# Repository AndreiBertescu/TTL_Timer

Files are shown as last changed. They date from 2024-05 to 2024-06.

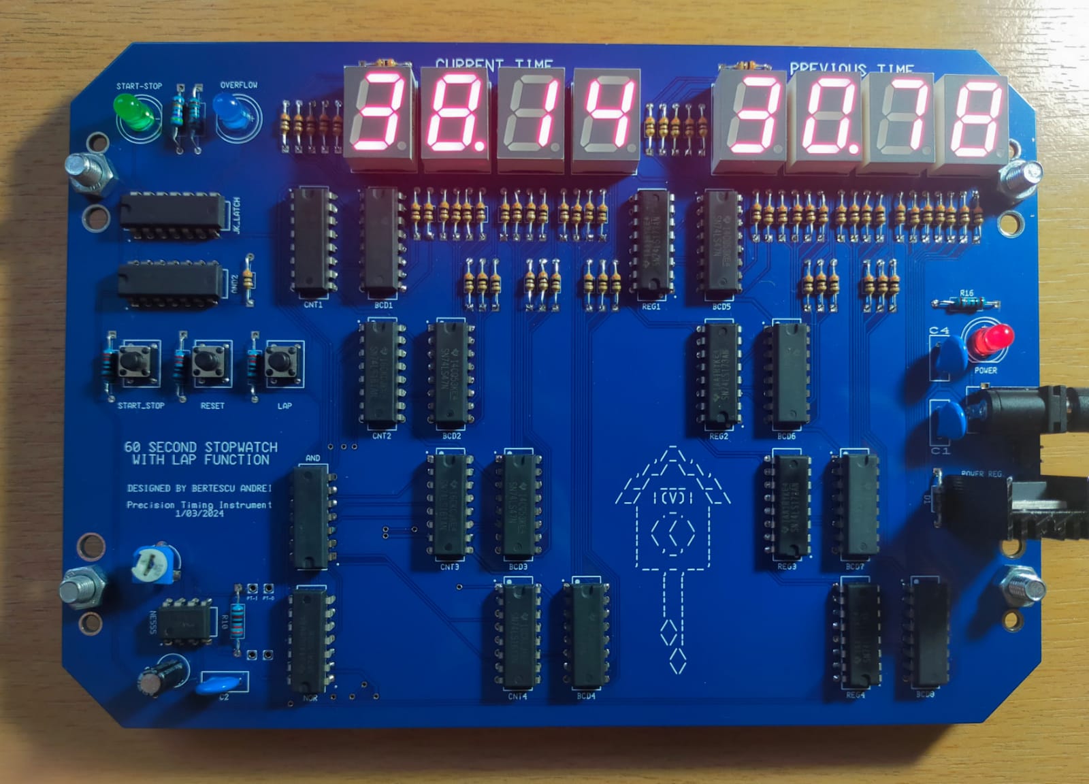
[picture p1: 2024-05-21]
Photos/Real1.jpg

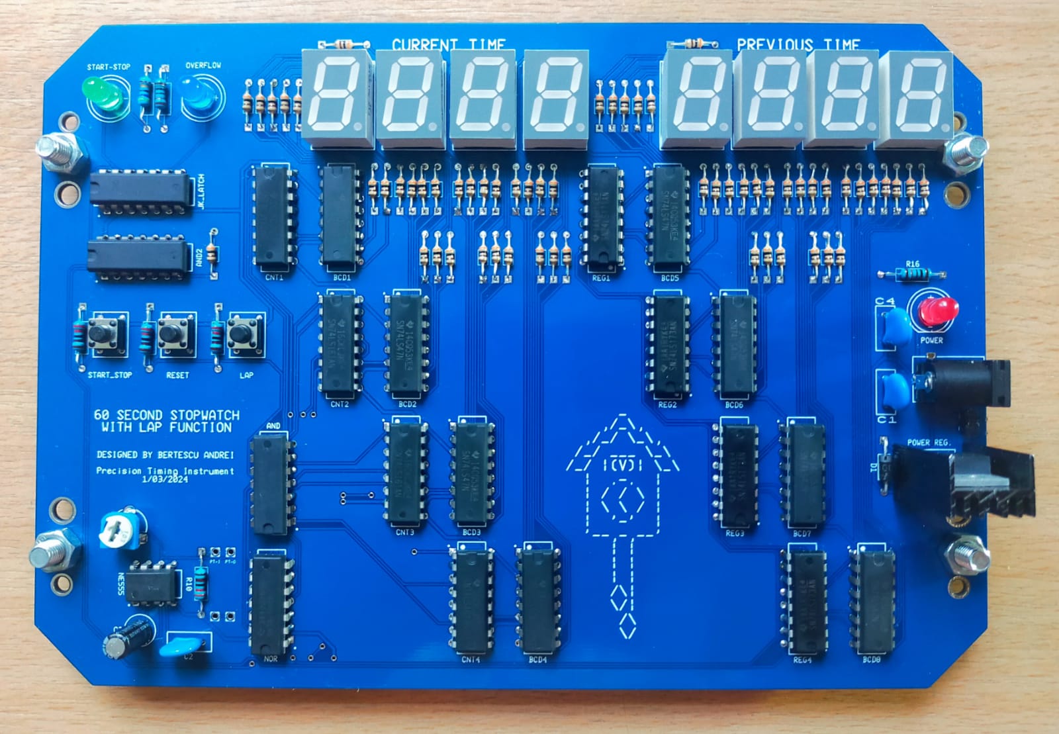
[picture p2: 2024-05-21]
Photos/Real2.jpg

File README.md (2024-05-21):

# TTL_Timer
A 60 second timer with stopwatch function, start/stop button and reset capabilities; made for a year 2 university project.

Real2

## Description and features
- There are three buttons:
  - A <strong>START_STOP</strong> button, which  pauses and unpauses, with the help of a JK flip-flop, the main timer.
  - A <strong>RESET</strong> button, which  resets both the timer and the lap time.
  - A <strong>LAP</strong> button, which , when pressed, stores the timer values to a set of four 4-bit tri-state registers.
- There are three LEDs:
  - A <strong>POWER</strong> LED, to see if the circuit board has a power supply connected.
  - A <strong>START_STOP</strong> LED, which  is tied to the button with the same name.
  - An <strong>OVERFLOW</strong> LED, which  toggles when the main timer goes over 59.99 seconds.
- 8 7-segment displays: 4 for the timer and 4 for the lap time.
- Resolution of 10ms.
- Adjustable timer for precision calibration.
- 9V barrel input with reverse polarity protection.
- 5V 2-pin header with reverse polarity protection.
- 3 sizes of mounting screws.
- All the various files (Logisim schematic, Multisim schematic, Ultiboard layout) are included, along with the Gerber exports and a Bill of materials.

## Testing and designing steps

The first step was to design the logic circuit in [Logisim Evolution](https://github.com/logisim-evolution/logisim-evolution), for an easy to change design, while also not having to worry about the various electrical rules.

Logisim

<br>The next steps were to draw the electrical schematic and test it. For these steps, the Multisim/Ultiboard duo from National Instruments was used. Multisim, in particular, was chosen over more mainstream programs such as KiCad for its real-time simulation feature, which helped ensure the PCB would work as intended from the first try.

<p align="center">
  
  
</p>

<br>Next was drawing the layout:
- The PCB is a 19.0 cm x 13.3 cm 2-layer board.
- It has 3mm, 4mm, and 5mm mounting holes intended for standoff screws.
- It has a GND copper plane on both layers.
- All signal traces are 0.254 mm, while the 5V power trace is double the size, at 0.508 mm.
- An additional hole for the power regulator heatsink was added.
- Four additional holes were added to allow replacing the 555-timer potentiometer with two resistors tied in series.
- Proper names were added for the various components, along with description text and a nice drawing.



The final steps were to order the parts, the PCB, and assemble the board.

- The various components were ordered from [TME](https://www.tme.eu/en/)
- The PCB was ordered from [Jlcpcb](https://jlcpcb.com/)

## Components
- 8x 7-segment displays
- 3x LEDs
- 3x 10nF ceramic capacitors
- 1x 1uF electrolytic capacitor
- 1x 1N4002 rectifier diode
- 1x 10k trimmer potentiometer
- 3x push switches
- 1x barrel connector
- 2x header pins
- 1x LM7805 power regulator
- 4x 4-bit tri-state registers
- 8x 4-bit BCD decoders
- 4x 4-bit counters
- 2x quad AND gate chips
- 1x quad NOR gate chip
- 1x dual JK flip-flop chip
- Various resistors

## Final statistics
- Total cost:
  - Components: 200 RON
  - PCB: 98 RON
- Total hours of work:
  - Designing schematic and testing: 4 hours
  - Making layout: 6 hours
  - Assembling PCB: 3 hours
 
## Extra photos
Real1
Real3

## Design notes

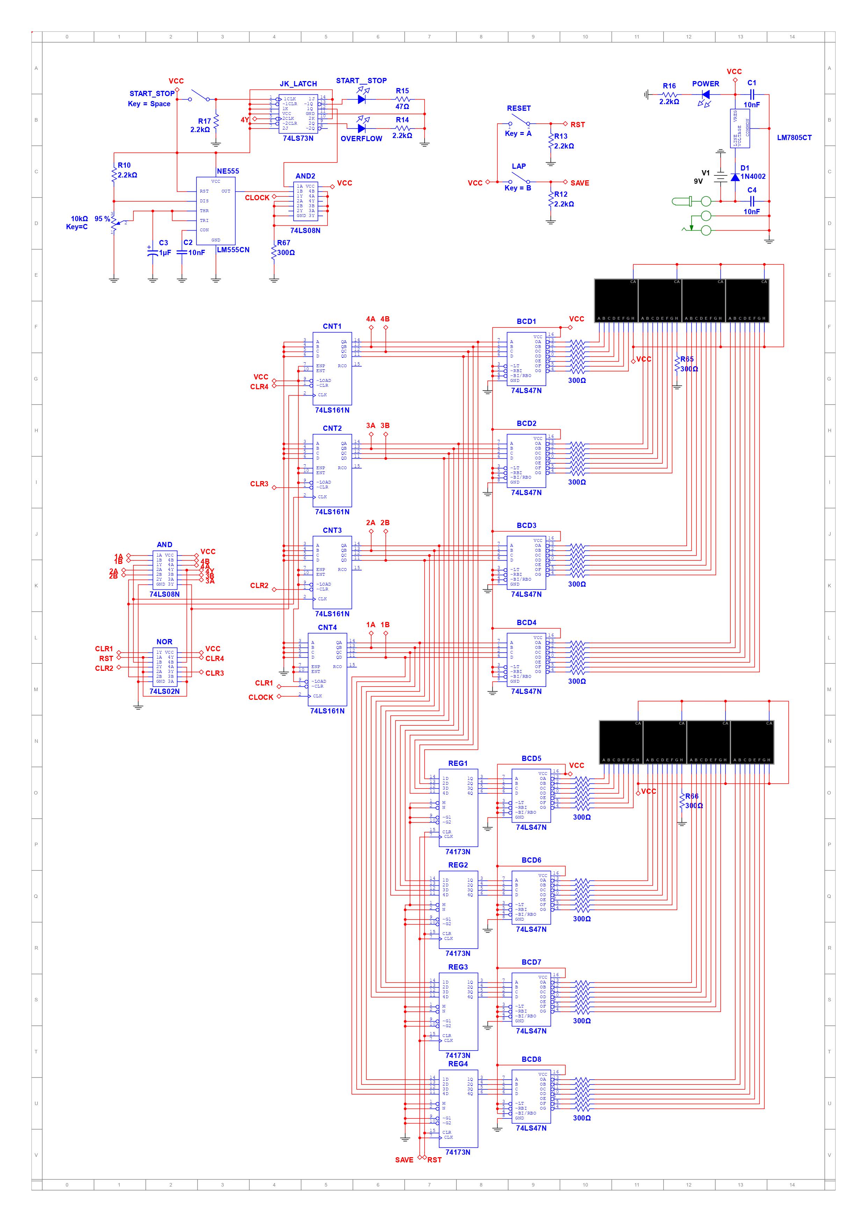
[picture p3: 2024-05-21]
Photos/Schematic.jpg

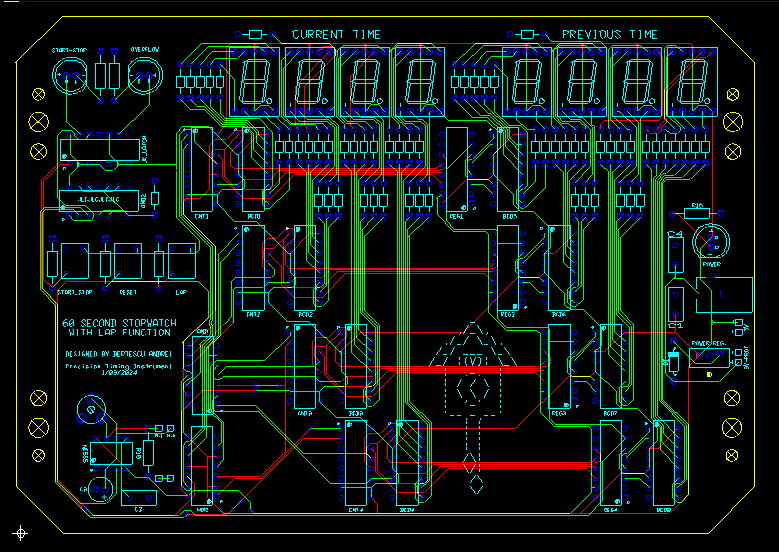
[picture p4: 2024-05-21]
Photos/PCB1.png

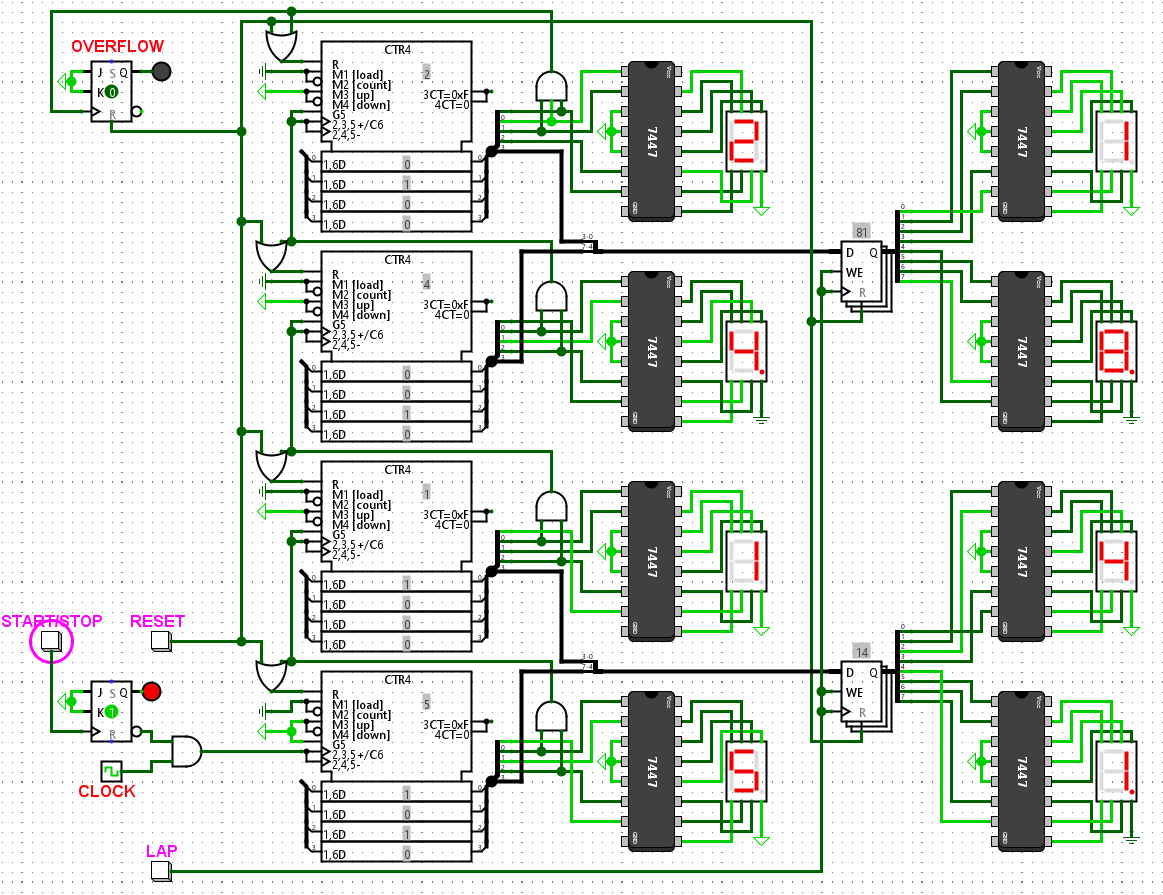
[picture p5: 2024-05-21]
Photos/Logisim.png

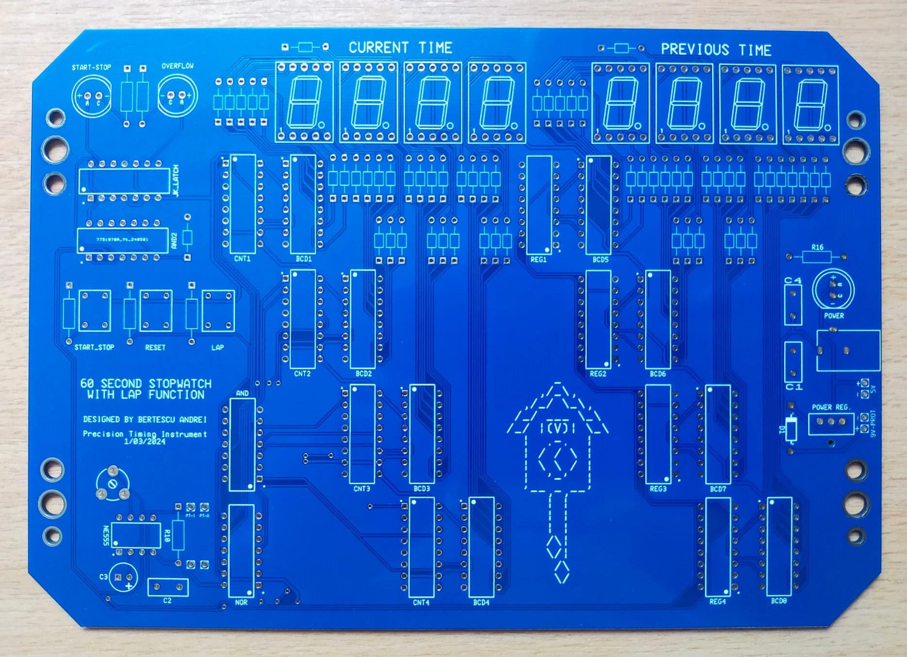
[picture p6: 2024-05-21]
Photos/Real3.jpg

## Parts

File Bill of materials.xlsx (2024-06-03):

Quantity | Description | RefDes | Package | Price | Total
4 | 74STD, 74173N | REG1, REG2, REG3, REG4 | IPC-2221A/2222\NO16 | 7.10 €
4 | 74LS, 74LS161N | CNT1, CNT2, CNT3, CNT4 | IPC-2221A/2222\NO16 | 3.82 €
8 | 74LS_IC, 74LS47N | BCD1, BCD2, BCD3, BCD4, BCD5, BCD6, BCD7, BCD8 | IPC-2221A/2222\NO16 | 11.94 €
1 | 74LS_IC, 74LS02N | NOR | IPC-2221A/2222\NO14 | 3.16 €
2 | 74LS_IC, 74LS08N | AND, AND2 | IPC-2221A/2222\NO14 | 1.15 €
59 | RESISTOR, 300Ω | R1, R2, R3, R4, R5, R6, R7, R8, R9, R18, R19, R20, R21, R22, R23, R24, R25, R26, R27, R28, R29, R30, R31, R32, R33, R34, R35, R36, R37, R38, R39, R40, R41, R42, R43, R44, R45, R46, R47, R48, R49, R50, R51, R52, R53, R54, R55, R56, R57, R58, R59, R60, R61, R62, R63, R64, R65, R66, R67 | IPC-2221A/2222\RES900-300X200 | 0.70 €
1 | VOLTAGE_REGULATOR, LM7805CT | U2 | Texas Instruments\TO-220-3(NDE) | 2.06 €
1 | POWER, PJ-102A | J1 | CUI\PJ-102A | 0.58 €
3 | CAPACITOR, 10nF | C1, C2, C4 | Ultiboard\CRM5B | 0.05 €
3 | LED_blue | OVERFLOW, POWER, START__STOP | Ultiboard\LED9R2_5Vb | -
2 | RESISTOR, 2.2kΩ | R10, R14, R16 | IPC-2221A/2222\IND1250-650X250 | -
3 | RESISTOR, 500Ω | R14 | IPC-2221A/2222\IND1250-650X250 | -
3 | RESISTOR, 1kΩ | R12, R13, R17 | IPC-2221A/2222\IND1250-650X250 | -
1 | DIODE, 1N4002 | D1 | Motorola\DO-35 | 0.12 €
1 | TIMER, LM555CN | NE555 | IPC-2221A/2222\N08E | 0.41 €
1 | CAP_ELECTROLIT, 1µF | C3 | IPC-2221A/2222\CAPPR250-630X1120 | 0.06 €
1 | POTENTIOMETER, 10kΩ | R11 | Ultiboard\TRIM-CON7.5 | 0.11 €
3 | SPST, | LAP, RESET, START_STOP | Ultiboard\Push Button | -
1 | RESISTOR, 47Ω | R15 | IPC-2221A/2222\IND1250-650X250 | -
1 | 74LS_IC, 74LS73N | JK_LATCH | IPC-2221A/2222\NO14 | 2.60 €
8 | SEVEN_SEG_DECIMAL_COM_A_BLUE | U1, U3, U4, U5, U6, U7, U8, U15 | Generic\7SEG8DIP14B | 3.93 € | 37.77 €

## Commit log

2024-05-21 Updated BOM
    [Bill of materials.xlsx]
2024-06-03 Updated schematic
